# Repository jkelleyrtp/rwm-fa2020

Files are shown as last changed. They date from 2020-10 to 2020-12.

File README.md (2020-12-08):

# Indoor GPS - Real World MicroControllers

A centimeter-accurate position tracking solution for Olin College's Real World Microcontroller course.

The Real-Time-Location-System (RTLS) in this project was designed using KiCad, manufactured by JLCPCB, and assembled by myself (SMD by hand!). My firmware tools of choice were the Rust programing language for firmware , Probe-rs and JLink for flashing and debugging, and, again, Rust for the visualization and web integration. The localization was done in-firmware using a novel and extremely power efficient 1-way-ranging algorithm.

## Packages
----

| Package | Purpose |
| --- | --- |
| Docs | Documentation of the indoor gps project |
| blinky | Kicad files for a very simple blinky project to learn fab |
| nrf-tests | Testing the deployment of rust code onto the nrf-52840 |
| dmw1000-carrier | Kicad files for a carrier board for the dwm1001 |
| nrf-accel | a crate that provides access to the ___ accelerometer |

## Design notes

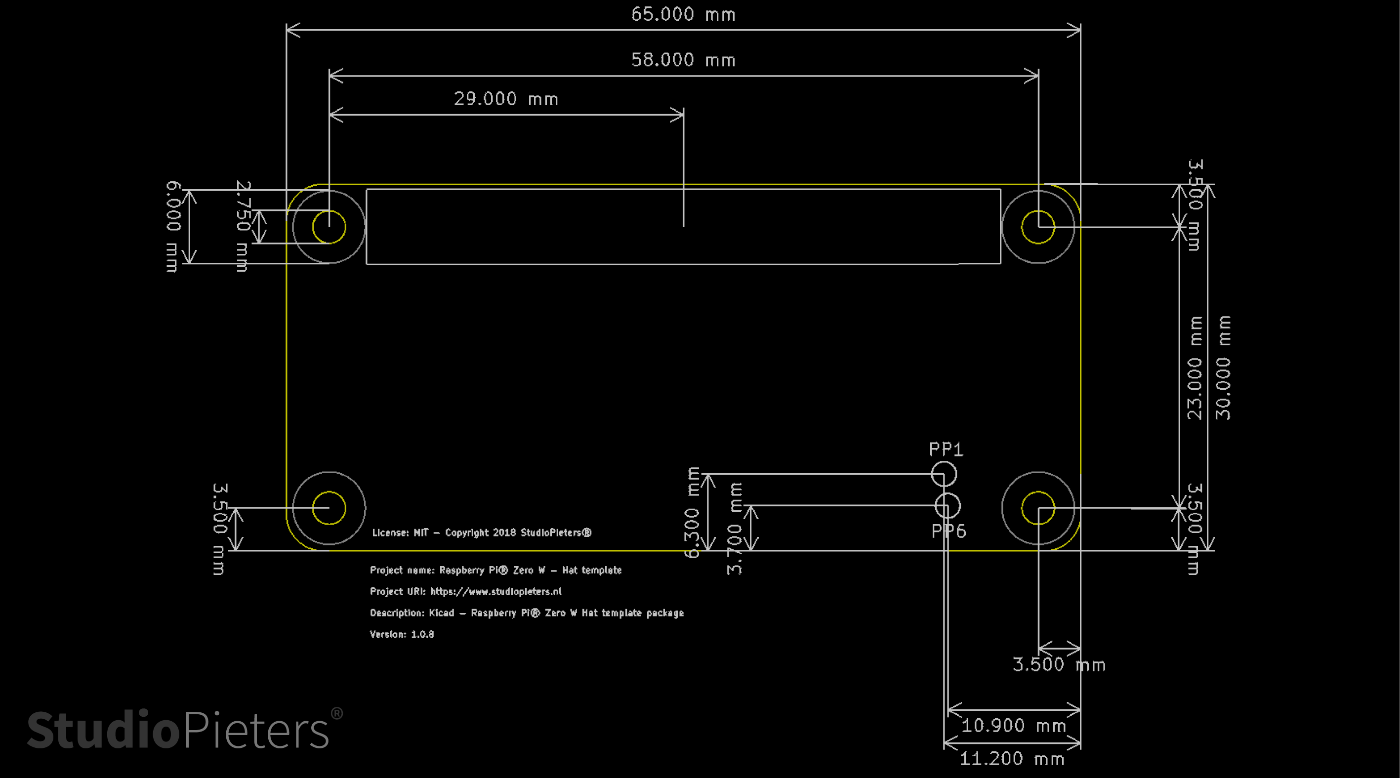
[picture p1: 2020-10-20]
packages/pcb-common/Raspberry Pi Zero W/meta/brd.png

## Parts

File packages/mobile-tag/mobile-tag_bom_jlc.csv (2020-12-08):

Comment | Designator | Footprint | LCSC Part #
10uF | C1 | C_0805_2012Metric_Pad1.15x1.40mm_HandSolder | C15850
10uF | C2 | C_Radial_D5.0mm_H5.0mm_P2.00mm | C15850
0.1uF | C3 | R_0603_1608Metric_Pad1.05x0.95mm_HandSolder | C49678
D | D1 | D_5W_P10.16mm_Horizontal | C22452
LED | D2 | LED_0805_2012Metric_Castellated | C34499
LED | D3,D4 | LED_D3.0mm | C34499
LD1117S12TR_SOT223 | DC_Converter1 | SOT-223-3_TabPin2 | C116068
100 | R1 | R_Axial_DIN0204_L3.6mm_D1.6mm_P5.08mm_Vertical | C17901
100 | R2,R3 | R_1206_3216Metric_Pad1.42x1.75mm_HandSolder | C17901
10k | R4 | R_1206_3216Metric_Pad1.42x1.75mm_HandSolder | C17902
R_Pack04 | RN1 | R_Array_Convex_4x0603 | C29718

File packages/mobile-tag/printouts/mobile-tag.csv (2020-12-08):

Reference | Value | Footprint | Datasheet | Description | Height | Manufacturer_Name | Manufacturer_Part_Number | Mouser Part Number | Mouser Price/Stock
D1 | LED |  | ~
D2 | LED |  | ~
D3 | LED |  | ~
D4 | D |  | https://www.adafruit.com/product/755
J1 | USB_B_Micro |  | https://www.adafruit.com/product/1833
J2 | Conn_ARM_JTAG_SWD_10 |  | http://infocenter.arm.com/help/topic/com.arm.doc.ddi0314h/DDI0314H_coresight_components_trm.pdf
J3 | Conn_01x06_Female |  | ~
Q1 | PN2222A | Package_TO_SOT_THT:TO-92_Inline | https://www.onsemi.com/pub/Collateral/PN2222-D.PDF
R1 | R |  | ~
R2 | 10k |  | ~
R3 | R |  | ~
S1 | SKQUCAA010 | SKQUCAA010 | https://www.mouser.co.uk/datasheet/2/15/skqu-1155891.pdf | Alps, SKQUCAA010, 2 Way Joystick Switch Plunger, Momentary, 12V dc | 10 | ALPS | SKQUCAA010 | 688-SKQUCA | https://www.mouser.co.uk/ProductDetail/ALPS/SKQUCAA010?qs=N5Jky1br14PIN8L1H%2F2niA%3D%3D
SW1 | SW_Push |  | https://www.adafruit.com/product/367
SW2 | SW_Push |  | https://www.adafruit.com/product/367
U1 | DWM1001 | RF_Module:DecaWave_DWM1001 | https://www.decawave.com/sites/default/files/dwm1001_datasheet.pdf
U2 | 128x64OLED |  | https://www.adafruit.com/product/326
U3 | CoinCellBreakoutOnOff |  | https://www.adafruit.com/product/1871
U4 | LD1117S12TR_SOT223 | Package_TO_SOT_SMD:SOT-223-3_TabPin2 | http://www.st.com/st-web-ui/static/active/en/resource/technical/document/datasheet/CD00000544.pdf

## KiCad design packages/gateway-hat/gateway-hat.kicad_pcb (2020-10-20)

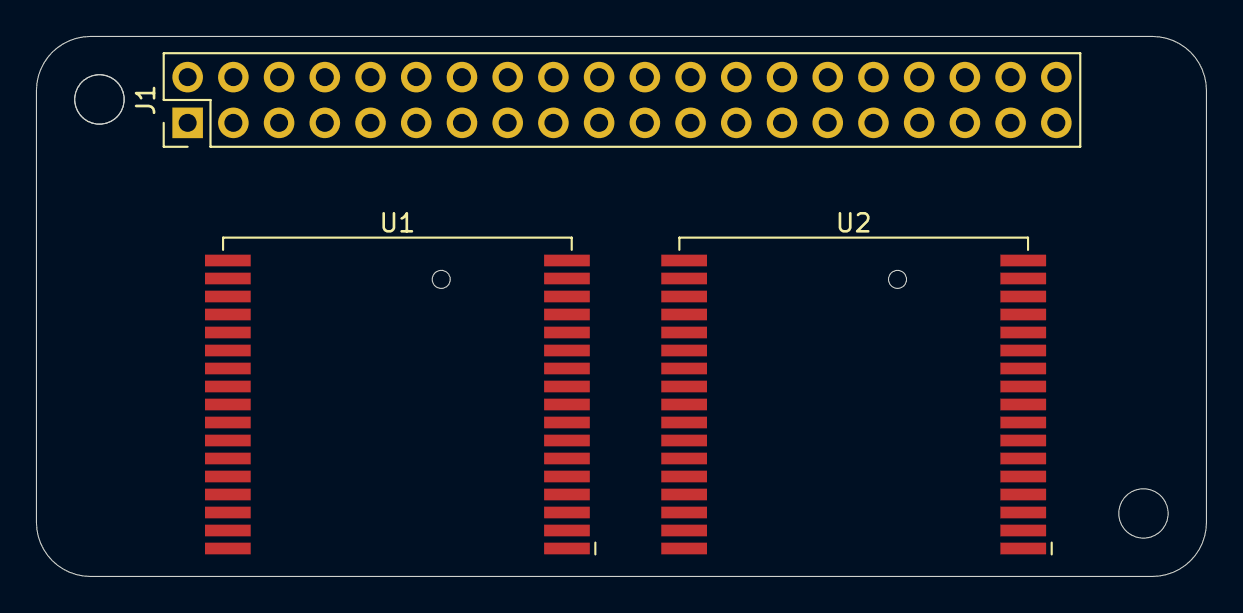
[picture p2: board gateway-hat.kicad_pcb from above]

Board: 2 copper layers, 65.0 x 30.0 mm, 3 parts (0 on the bottom side), 2 nets, no tracks yet.

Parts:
J1: Conn_02x20_Odd_Even; PinHeader_2x20_P2.54mm_Vertical
U1, U2: DWM1001; DecaWave_DWM1001

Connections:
unnamed: U1.1 (GND), U1.11 (GND), U1.24 (GND), U1.34 (GND)
unnamed: U2.1 (GND), U2.11 (GND), U2.24 (GND), U2.34 (GND)

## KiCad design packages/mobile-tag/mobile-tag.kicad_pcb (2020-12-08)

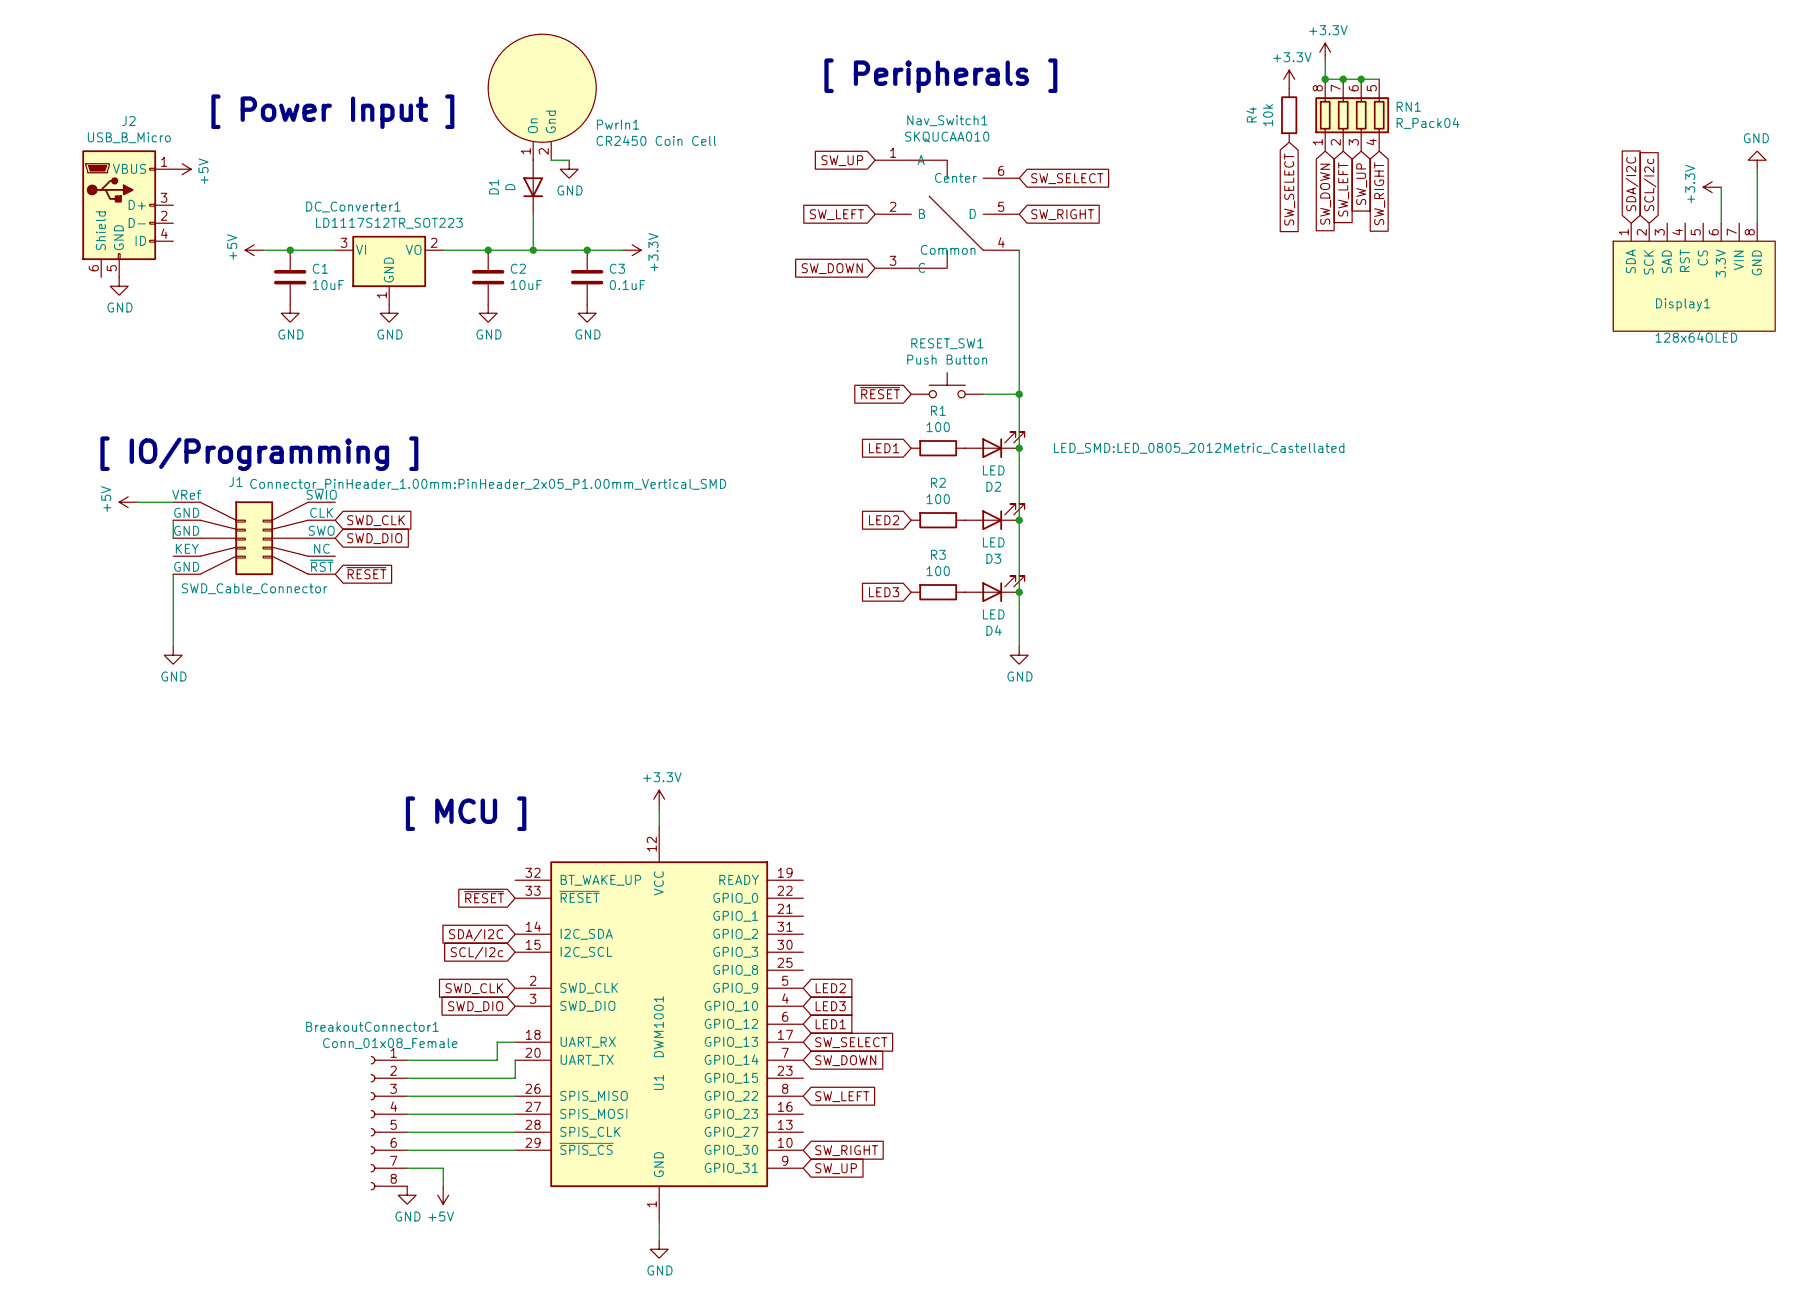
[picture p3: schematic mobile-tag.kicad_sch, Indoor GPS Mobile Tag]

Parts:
BreakoutConnector1: Conn_01x08_Female; PinSocket_1x08_P2.54mm_Horizontal
C1: 10uF; C_0805_2012Metric_Pad1.15x1.40mm_HandSolder; JLCPCB C15850
C2: 10uF; C_Radial_D5.0mm_H5.0mm_P2.00mm; JLCPCB C15850
C3: 0.1uF; R_0603_1608Metric_Pad1.05x0.95mm_HandSolder; JLCPCB C49678
D1: D; D_5W_P10.16mm_Horizontal; JLCPCB C22452
D2: LED; LED_0805_2012Metric_Castellated; JLCPCB C34499
D3, D4: LED; LED_D3.0mm; JLCPCB C34499
DC_Converter1: LD1117S12TR_SOT223; SOT-223-3_TabPin2; JLCPCB C116068
Display1: 128x64OLED; Adafruit_SSD1306
J1: SWD_Cable_Connector; PinHeader_2x05_P1.00mm_Vertical_SMD
J2: USB_B_Micro; USB_Micro-B_Wuerth_629105150521
Nav_Switch1: SKQUCAA010; Manufacturer_Part_Number SKQUCAA010; Mouser Part Number 688-SKQUCA
PwrIn1: CR2450 Coin Cell; BatteryHolder_Keystone_3009_1x2450
R1: 100; R_Axial_DIN0204_L3.6mm_D1.6mm_P5.08mm_Vertical; JLCPCB C17901
R2, R3: 100; R_1206_3216Metric_Pad1.42x1.75mm_HandSolder; JLCPCB C17901
R4: 10k; R_1206_3216Metric_Pad1.42x1.75mm_HandSolder; JLCPCB C17902
RESET_SW1: Push Button; SW_PUSH_6mm_H5mm
RN1: R_Pack04; R_Array_Convex_4x0603; JLCPCB C29718
U1: DWM1001; DecaWave_DWM1001

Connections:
GND: BreakoutConnector1.8, C1.2, C2.2, C3.2, D2.1 (K), D3.1 (K), D4.1 (K), DC_Converter1.1 (GND), Display1.8 (GND), J1.9 (GND), J2.5 (GND), Nav_Switch1.4 (Common), PwrIn1.2 (Gnd), RESET_SW1.2, U1.1 (GND), U1.11 (GND), U1.24 (GND), U1.34 (GND)
LED1: R1.2, U1.6 (GPIO_12)
LED2: R2.2, U1.5 (GPIO_9)
LED3: R3.2, U1.4 (GPIO_10)
unnamed: BreakoutConnector1.1, U1.18 (UART_RX)
unnamed: BreakoutConnector1.2, U1.20 (UART_TX)
unnamed: BreakoutConnector1.3, U1.26 (SPIS_MISO)
unnamed: BreakoutConnector1.4, U1.27 (SPIS_MOSI)
unnamed: BreakoutConnector1.5, U1.28 (SPIS_CLK)
unnamed: BreakoutConnector1.6, U1.29 (~SPIS_CS)
unnamed: D1.2 (A), PwrIn1.1 (On)
unnamed: D2.2 (A), R1.1
unnamed: D3.2 (A), R2.1
unnamed: D4.2 (A), R3.1
unnamed: J1.3 (GND), J1.5 (GND)
SCL/I2c: Display1.2 (SCK), U1.15 (I2C_SCL)
SDA/I2C: Display1.1 (SDA), U1.14 (I2C_SDA)
SWD_CLK: J1.4 (CLK), U1.2 (SWD_CLK)
SWD_DIO: J1.6 (SWO), U1.3 (SWD_DIO)
SW_DOWN: Nav_Switch1.3 (C), RN1.1 (R1.1), U1.7 (GPIO_14)
SW_LEFT: Nav_Switch1.2 (B), RN1.2 (R2.1), U1.8 (GPIO_22)
SW_RIGHT: Nav_Switch1.5 (D), RN1.4 (R4.1), U1.10 (GPIO_30)
SW_SELECT: Nav_Switch1.6 (Center), R4.2, U1.17 (GPIO_13)
SW_UP: Nav_Switch1.1 (A), RN1.3 (R3.1), U1.9 (GPIO_31)
~RESET: J1.10 (~RST), RESET_SW1.1, U1.33 (~RESET)

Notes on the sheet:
[ IO/Programming ]
[ Power Input ]
[ MCU ]
[ Peripherals ]

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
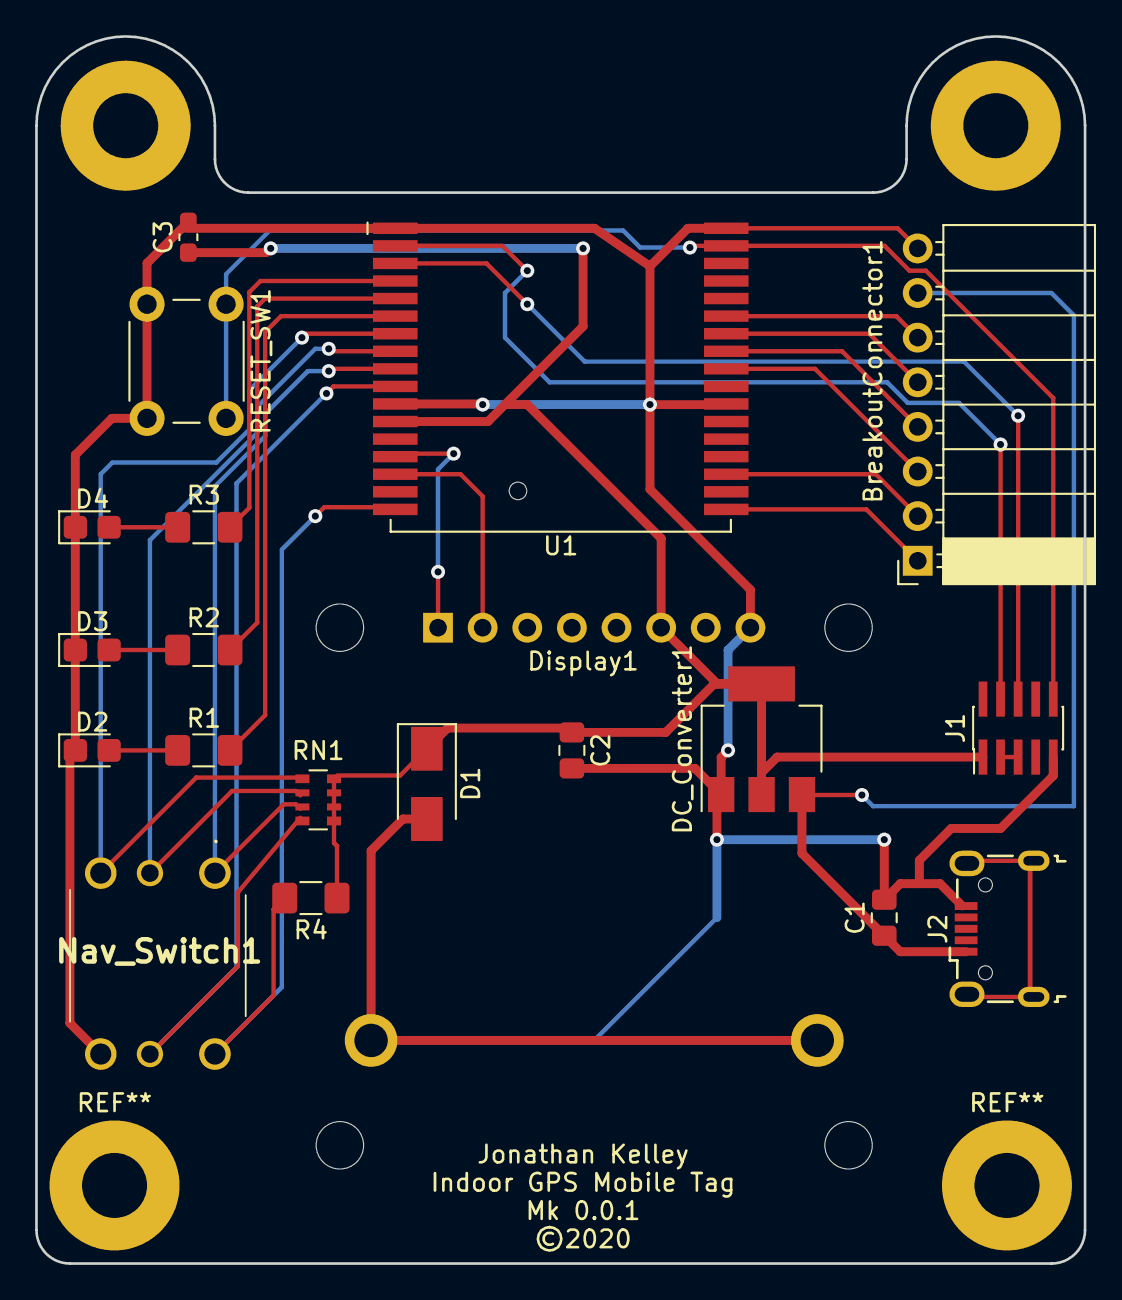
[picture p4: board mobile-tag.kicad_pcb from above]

Board: 2 copper layers, 59.7 x 69.9 mm, 21 parts (1 on the bottom side), 27 nets.

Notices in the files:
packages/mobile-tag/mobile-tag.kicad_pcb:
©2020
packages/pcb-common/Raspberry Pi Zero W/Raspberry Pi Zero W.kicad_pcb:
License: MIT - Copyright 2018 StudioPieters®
